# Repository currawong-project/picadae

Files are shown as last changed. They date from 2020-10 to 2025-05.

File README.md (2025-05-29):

# Currawong Picadae

The Currawong Picadae is a portable piano player unit inspired by
[PlayerPiano II](https://logosfoundation.org/instrum_gwr/playerpiano.html) as created by [Gotfried-Willem Raes](https://en.wikipedia.org/wiki/Godfried-Willem_Raes)
 of the [Logos Foundation](https://www.logosfoundation.org/).  This project
 was a [Currawong Project](https://currawongproject.org) collaboration with
 Bill Bowen and Chico McMurtrie of [Amorphic Robot Works](https://amorphicrobotworks.org/).

# CML Picadae hardware and a control files.

- [__kicad__](kicad/README.md) contains the keyboard and pedal schematics and printed circuit board layout.
- [__control__](control/README.md) contains the keyboard solenoid ATtiny85 firware, controller Arduino firmware and, Python control API and program.

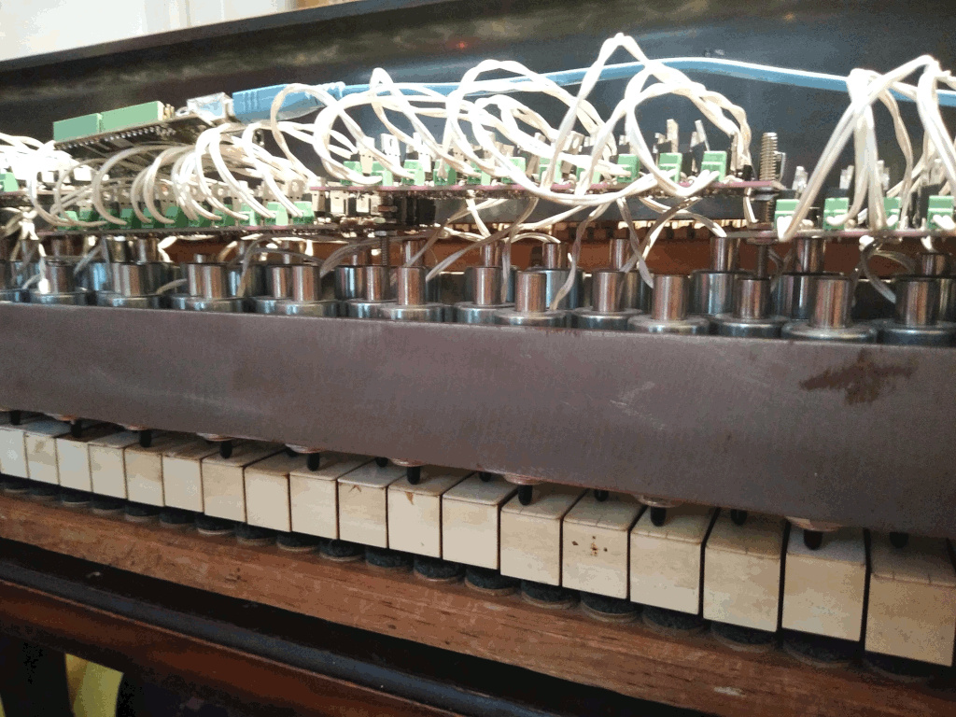
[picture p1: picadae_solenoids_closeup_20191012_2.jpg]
Picadae


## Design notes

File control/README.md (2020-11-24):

This folder contains the _picadae_ control code.

The _picadae_ control program consists of three parts:

- _tiny_ : [ATtiny85 solenoid driver firmware](tiny/README.md)

- _ctrl_ : [ATmega328 interface unit](ctrl/README.md) 

- _app_  : [Python monitor and command utility](app/README.md)

# Architecture

The keyboard control hardware consists of 8 driver boards mounted
above the solenoids on the keyboard assembly.  Each driver board has
11 key driver circuits which control 11 piano keys. Each key driver
circuit consists of an ATtiny85 microcontroller which controls a set
of power transistors which in turn control the state of the solenoid.
The solenoid can be in one of three states:

- off
- attack
- hold 

The attack state is triggered by pulsing the 
the solenoid with a fast (250 microsecond to
30 millisecond) 36 volt pulse. The duration
of the pulse determines the attack dynamic.
Longer pulses produce louder notes.
At the end of the attack state the solenoid
transitions into a hold state. During
this time the key is held down with just
enough force to sustain the note.

All 88 ATtiny85 microncontrollers are attached
to a single I2C bus which is mastered by an ATmega328 MCU
which acts as a serial to I2C translator for the host computer.

The host API is implemented as the Python class 'Picadae' in app/picadae_api.py.
The control shell program app/picadae_shell.py shows an example
usage of the API.

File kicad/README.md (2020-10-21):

# Bill of materials

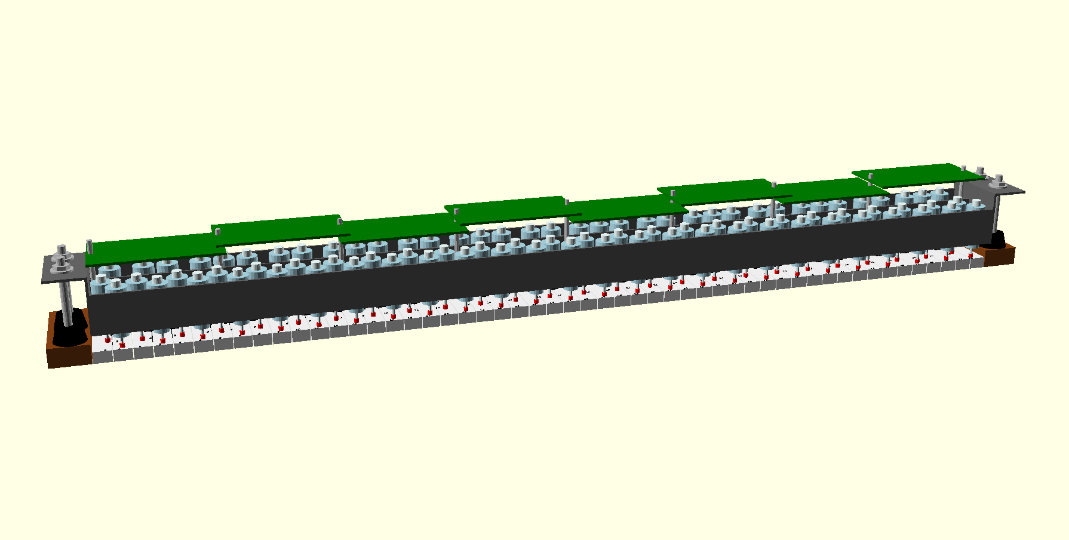
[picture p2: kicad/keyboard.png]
Keyboard assembly


## Keyboard Power and Control 

These parts serve the entire keyboard solenoid assembly.

Id   | Type            | Description          | Qty | Source   | Part Number
-----|-----------------|----------------------|-----|----------|--------------------
J3   | 6P Terminal     | Screw Terminal       |   2 | Mouser   | 651-1725698
P1   | HDS800PS24      | 24V Power Supply     |   1 | Digikey  | 1470-2689-ND
P2   | HDS800PS12      | 12V Power Supply     |   1 | Digikey  | 1470-2687-ND
P3   | TXL 015-05S     | 5V Power Supply      |   1 | Digikey  | 1951-1325-ND
M0   | Controller MCU  | Arduino Uno R3       |   1 | Digikey  | 1050-1024-ND
None | 1/16 x 1/8 x 1/2| Rubber feet(pkg 100) |   1 | McMaster | 9753K11

## Key Driver Board (11 channels per board) 

There are 8 driver boards per keyboard solenoid assembly. Each board
has 11 driver circuits.  

Id   | Type            | Description         | Qty | Source   | Part Number
-----|-----------------|---------------------|-----|----------|--------------------
U1   | ATtiny85-20MU   | Microcontroller     |  11 | Mouser   | 556-ATTINY85-20PU
None | 8DIP IC         | Socket              |  11 | Mouser   | 571-1-2199298-2
None | 0.1uF           | Capacitor           |   1 | Digikey  | 399-14010-1-ND
R1-2 | 4.7k            | Resistor            |  22 | Mouser   | 293-4.7K-RC
D1   | BYV32-200       | Diode               |  11 | Mouser   | BYV32-200GOS-ND
D2   | SF52            | Rectifier           |  11 | Mouser   | 583-SF52-B
D4   | Z10Y            | Diode               |  11 | Mouser   | 78-BZX55C10-TAP
Q1   | 2N3906          | BJT                 |  11 | Mouser   | 512-2N3906BU
Q2   | IRL640          | MOSFET              |  11 | Mouser   | 512-IRL640A
Q3   | IRF610          | MOSFET              |  11 | Mouser   | 844-IRF610PBF
S1   | Solenoid        | Ledex 195207-228    |  11 | Testco   | 195207-228
C1   | 100uF           | Capacitor           |   2 | Digikey  | 493-1668-ND
J1   | 2P Terminal     | Screw Terminal      |  11 | Mouser   | 651-1725656
J2   | 6P Female .1    | Pin Terminal        |   1 | Digikey  | H123900-ND

## Damper Pedal Driver Board

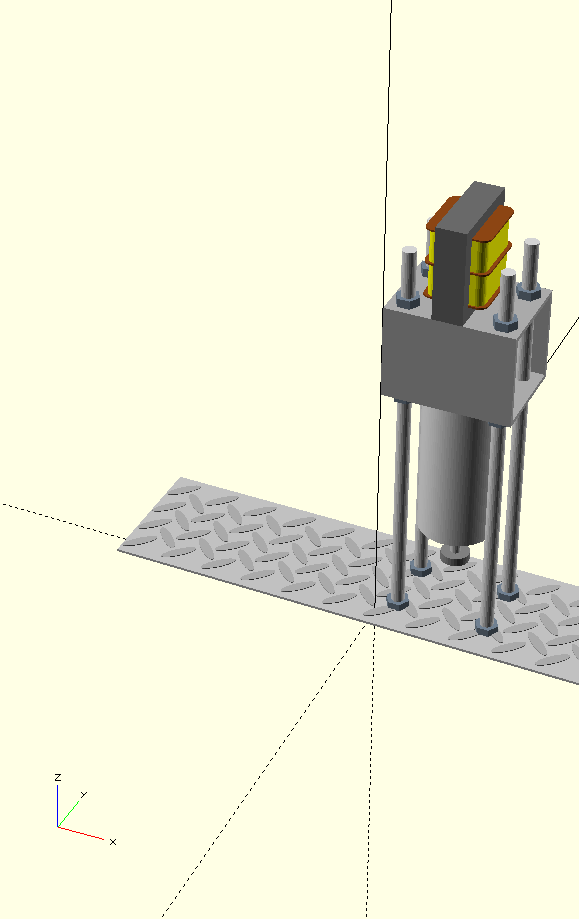
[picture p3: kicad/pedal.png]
Pedal driver assembly


Id   | Type            | Description         | Qty | Source   | Part Number
-----|-----------------|---------------------|-----|----------|--------------------
R1-4 | 180 ohm         | Resistor            |   4 |  Mouser  | 660-MF1/2LCT52R181G
R5-6 | 470 ohm         | Resistor            |   2 |  Mouser  | 71-CCF07470RGKE36
C1-2 | 1uF             | Capacitor           |   2 |  Newark  | 65R3171
C3-4 | 4700uF          | Capacitor           |   2 |  Newark  | GBPC2501W
Q1-2 | BS170           | MOSFET              |   2 |  Mouser  | 512-BS170
Q3-4 | IRF1310NPBF     | MOSFET              |   2 |  Mouser  | 942-IRF1310NPBF
U1   | TLP523          | Dual Opto-isolator  |   1 |  Newark  | 05M1443
U2-3 | LM7810ACT       | 10V Voltage Regulato|   2 |  Mouser  | 512-KA7810ETU
D1   | Bridge Rectifier| 100V 25A            |   1 |  Newark  | GBPC2501W
D2-3 | STTH30R061PI    | Diode               |   1 |  Mouser  | 512-RURP3060
L1   | Push Solenoid   | 24 Volt             |   1 |  Laukhuff| 301010
T1   | Transformer     |                     |   1 |  Digikey | 595-1961-ND

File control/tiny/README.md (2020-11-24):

# ATtiny85 I2C protocol

Arguments in curly braces are optional.

------------------------------------------------------------------------------------------

__Hold PWM Duty Cycle__

Function                 | Opcode | Arguments
-------------------------|--------|---------------------------
Set hold PWM duty cycle  |    0   | (duty) { (freq) { (div) }}

Arguments | Range | Default | Note
----------|-------|---------|------------------------------------------------------
(duty)    | 0-255 |    127  | 0=0%, 255=100%
(freq)    | 0-255 |    255  | Sets PWM top value
(div)     | 1-15  |      5  | Set the PWM base clock frequency (See table below) 

PWM frequency and period for each possible (div) setting.

Value | Div  | Frequency   | Period
------|------|-------------|-------
 1    |    1 |    16    M  | 62.5 n 
 2    |    2 |     8    M  |  125 n
 3    |    4 |     4    M  |  250 n
 4    |    8 |     2    M  |  500 n
 5    |   16 |     1    M  |    1 u
 6    |   32 |   500    K  |    2 u
 7    |   64 |   250    K  |    4 u
 8    |  128 |   125    K  |    8 u
 9    |  256 | 62500    Hz |   16 u
10    |  512 | 31250    Hz |   32 u
11    | 1024 | 15625    Hz |   64 u
12    | 2048 | 7812.5   Hz |  128 u
13    | 4096 | 3906.25  Hz |  256 u
14    | 8192 | 1953.125 Hz |  512 u
15    |16384 | 976.6625 Hz | 1024 u 

------------------------------------------------------------------------------------------

__Note-on Velocity__

Function                 | Opcode | Arguments
-------------------------|--------|---------------------------
Note on velocity         |    1   | (vel)

Arguments | Range | Default | Note
----------|-------|---------|------------------------------------------------------
(vel)     | 0-127 |  n/a    | Note on velocity.

Execute a note onset.
The (vel) value is translated to an attack pulse duration
by looking up the pulse tick count in the velocity table.

------------------------------------------------------------------------------------------

__Note-on Microseconds__

Function                 | Opcode | Arguments
-------------------------|--------|-------------------------------------------------
Note on ticks            |   2    | (pulse-ticks-high-byte) (pulse-ticks-low-byte)

Execute a note onset.
The 16 bit attack duration in ticks is calculated from microseconds.

    pulse-ticks = (usec / 1e6) * (16e6/256)

Where 16e6 is the system clock frequency and 256 is the timer0 clock divider.
`TCCR0B:C02,C01,C00 = 100b (4)`

ticks to micoseconds:

    usecs = (pulse-ticks * 1e6)*(256/16e6)

------------------------------------------------------------------------------------------

__Note-off__

Function                 | Opcode | Arguments
-------------------------|--------|---------------------------
Note off                 |   3    | None

Turn off a sounding note by settting the hold-voltage to 0.

------------------------------------------------------------------------------------------

__Set Read Address__

Function                 | Opcode | Arguments
-------------------------|--------|---------------------------
Set read address         |    4   | (src) {(addr)}

Set the source and address of the next I2C read request.

The read can come from one of three memory banks:
Register File, MIDI velocity table or EEPROM.
See the _Memory Source Id Table_ below for the (src) id values.

Arguments   | Range | Default | Note
------------|-------|---------|-------------------------------------------------------
(src)       | 0-2   |  n/a    | Memory location id. See _Memory Source Id Table_.
(addr)      | 0-255 |  n/a    | Offset from base address set by (src)

Memory Source Id Table

Id | Memory         | Note
---|----------------|-------------------------------
 0 | Register file  | See register table file
 1 | Velocity table | MIDI velocity to pulse ticks lookup table
 2 | EEPROM         | EEPROM data memory

------------------------------------------------------------------------------------------

__Write Memory__

Function                 | Opcode | Arguments
-------------------------|--------|--------------------------------------------
Write memory             |    5   | (addrFl + dest) {(addr)} (value0) ... (valueN)

Arguments   | Range | Default | Note
------------|-------|---------|----------------------------------------------------------------
(addrFl)    | 0,127 |    0    | Address flag. Set if second byte is an (addr) and not (value0)
(dest)      | 0-2   |  n/a    | Memory destination location. See _Memory Destination Id Table_.
(addr)      | 0-255 |  n/a    | Optional offset from base address set by (dest)

Memory Destination Id Table

Id | Memory         | Note
---|----------------|-------------------------------
 4 | Register file  | See register table file
 5 | Velocity table | MIDI velocity to pulse ticks lookup table
 6 | EEPROM         | EEPROM data memory

------------------------------------------------------------------------------------------

__Write Velocity Table to EEPROM__

Function                 | Opcode | Arguments
-------------------------|--------|---------------------------
Write velocity table     |    6   | 

Writes the MIDI velocity table from memory to EEPROM.

------------------------------------------------------------------------------------------

__Set Hold Delay__

Function                 | Opcode | Arguments
-------------------------|--------|---------------------------
Set hold delay           |    7   | { high {low}}

Set the length of the delay, in ticks, between when the attack pulse ends and when the
hold voltage is applied.
The high and low byte values are calculated identically to the
attack pulse duration values.

------------------------------------------------------------------------------------------

__Set *flags* variable__

Function                 | Opcode | Arguments
-------------------------|--------|---------------------------
Set flags variable       |    8   | (flags)

  7  |  6  |  5  |  4  |  3  |  2  |  1  |  0  
-----|-----|-----|-----|-----|-----|-----|-----
 n/a | n/a | n/a | n/a | n/a | n/a | n/a | HOA

_HOA_ : Set to apply the hold voltage at the beginning of the attack.

------------------------------------------------------------------------------------------

## Register File Address

Address | Label           | Note
--------|-----------------|------------------------------------------------------------------------------------------------
0       | Reg_Rd_Addr     | Next register file address to read.
1       | Table_Rd_Addr   | Next MIDI velocity address to read.
2       | EEPROM_Rd_Addr  | Next EEPROM address to read.
3       | Read_Src_Addr   | Source of the next I2C read request. See Memory Location Id table below.
4       | Reg_Wr_Addr     | Next register file address to write.
5       | Table_Rd_Addr   | Next MIDI velocity address to write.
6       | EEPROM_Rd_Addr  | Next EEPROM address to write.
7       | Write_Dst_Addr  | Destination of the next 'write operation'. See Memory Location id table below.
8       | Tmr_High_Addr   | Current attack pulse tick count high byte
9       | Tmr_Low_Addr    | Current attack pulse tick count low byte
10      | Tmr_Div_Addr    | Attack pulse counter frequency divider.
11      | Pwm_Duty_Addr   | Duty cycle of the hold PWM generator
12      | Pwm_Freq_Addr   | PWM counter max values. Determines the PWM frequency.
13      | Pwm_Div_Addr    | PWM clock divider
14      | State_Addr      | Current solenoied state.
15      | Error_Addr      | Error status
16      | Max_Tmr_Hi_Addr | Max attack pulse high byte tick count.
17      | Delay_High_Addr | Hold delay onset tick count high byte
18      | Delay_Low_Addr  | Hold delay onset tick count low byte
19      | Flags_Addr      | Binary variable field.

------------------------------------------------------------------------------------------

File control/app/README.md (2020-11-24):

# Picadea control and monitor shell

Shell commands:

key | Function         | Arguments                                  | Notes
----|------------------|--------------------------------------------|----------------------------------------------------------
q   | quit             |                                            |
?   | print usage      |                                            |
w   | write            | (i2c_addr) (reg_addr) (data0) ... (dataN)  |
r   | read             | (i2c_addr) (src) (reg_addr) (byteN)        | See [Memory Source Id Table](#memory-source-id-table).
v   | note-on          | (pitch) (vel)                              |
u   | note-on          | (pitch) (usec) (div)                       | See [Pulse Timer Divisor Table](#pulse-timer-divisor).
o   | note-off         | (pitch)                                    |
T   | set table        | (pitch) (vel) (usec)                       |
t   | get table        | (pitch) (vel)                              |
D   | set duty         | (pitch) (percent) {(hz) {(div)}}           |
d   | get duty         | (pitch)                                    |
H   | set hold delay   | (pitch) (usec)                             |
h   | get hold delay   | (pitch)                                    |
F   | set pwm freq     | (pitch) (hz)                               | 254=~123Hz
f   | get pwm freq     | (pitch)                                    |
I   | set pwm div      | (pitch) (div)                              | See [PWM Divisor Table](#pwm-divisor).
i   | get pwm div      | (pitch)                                    |
A   | set flags        | (pitch) (flags)                            |
a   | get flags        | (pitch)                                    |
W   | write table      | (pitch)                                    |
N   | note w/ duration | (pitch) (atkUs) (durMs)                    |
S   | seq              | (pitch) (atkUs) (durMs) (deltaUs) (noteN)  |
L   | log              | (level) (0-1)                              |

## PWM Divisor

Value | Div  | Frequency   | Period
------|------|-------------|-------
 1    |    1 |    16    M  | 62.5 n 
 2    |    2 |     8    M  |  125 n
 3    |    4 |     4    M  |  250 n
 4    |    8 |     2    M  |  500 n
 5    |   16 |     1    M  |    1 u
 6    |   32 |   500    K  |    2 u
 7    |   64 |   250    K  |    4 u
 8    |  128 |   125    K  |    8 u
 9    |  256 | 62500    Hz |   16 u
10    |  512 | 31250    Hz |   32 u
11    | 1024 | 15625    Hz |   64 u
12    | 2048 | 7812.5   Hz |  128 u
13    | 4096 | 3906.25  Hz |  256 u
14    | 8192 | 1953.125 Hz |  512 u
15    |16384 | 976.6625 Hz | 1024 u 

## Pulse Timer Divisor

Value | Divisor | Frequency  | Period
------|---------|------------|--------------
  1   |      1  | 16000000   |     62.5n
  2   |      8  |  2000000   |    500.0n
  3   |     64  |   250000   |      4.0u
  4   |    256  |    62500   |     16.0u
  5   |   1024  |    15625   |     64.0u

## Memory Source Id Table

Id | Memory         | Note
---|----------------|-------------------------------
 0 | Register file  | See register table file
 1 | Velocity table | MIDI velocity to pulse ticks lookup table
 2 | EEPROM         | EEPROM data memory

## Memory Destination Id Table

Id | Memory         | Note
---|----------------|-------------------------------
 4 | Register file  | See register table file
 5 | Velocity table | MIDI velocity to pulse ticks lookup table
 6 | EEPROM         | EEPROM data memory

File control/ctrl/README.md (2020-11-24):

# ATmega328 Interface Unit

This MCU acts as a serial to I2C translator for the host
computer.  The serial protocol implements two
interfaces.  One for read requests and another for write commands.

The data format of the write commands is given
in the ATtiny85 I2C protocol document.

Read requests return blocks of memory begining with the address
specified in the last 'Set read address' command.

## Read: Channel to Host

Read a `<count>` bytes from a channel beginning at offset = 'offset'

    'r' <i2c-addr> <offset> <count>

## Write: Host to Channel

Write `<count>` bytes from from the host to a channel

    'w' <i2c-addr> <register> <count> <value-0> <value-1> ... <value-n>

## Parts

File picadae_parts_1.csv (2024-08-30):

Picadae Parts and Prices: 11/2020
Power and Control
Id | Type | Description | Qty | Price |  | Source | Source Part Number
J3 | 6P Terminal | Screw Terminal | 2 | 4.52 | 9.04 | Mouser | 651-1725698
P1 | HDS800PS24 | 24V Power Supply | 1 | 380 | 380 | Digikey | 1470-2689-ND
P2 | HDS800PS12 | 12V Power Supply | 1 | 380 | 380 | Digikey | 1470-2687-ND
P3 | TXL 015-05S | 5V Power Supply | 1 | 31.3 | 31.3 | Digikey | 1951-1325-ND
M0 | Controller MCU | Arduino Uno R3 | 1 | 22 | 22 | Digikey | 1050-1024-ND
 | 1/16 x 1/8 x 1/2 | Rubber feet (pkg 100) | 1 | 3.37 | 3.37 | McMaster | 9753K31 or (9753K11?)
 |  |  |  |  | 825.71
Key Driver Board (11 channels per board)
Id | Type | Description | Qty | Price |  | Source | Source Part Number
U1 | ATtiny85-20MU | Microcontroller | 11 | 1.44 | 15.84 | Mouser | 556-ATTINY85-20PU
 | 8DIP IC Socket |  | 11 | 0.09 | 0.99 | Mouser | 571-1-2199298-2
 | 0.1uF | Capacitor | 1 |  |  | Digikey | 399-14010-1-ND
R1-2 | 4.7k | Resistor | 22 | 0.18 | 3.96 | Mouser | 293-4.7K-RC
D1 | BYV32-200 | Diode | 11 | 0.92 | 10.12 | Mouser | BYV32-200GOS-ND
D2 | SF52 | Rectifier | 11 | 0.58 | 6.38 | Mouser | 583-SF52-B
D4 | Z10Y | Diode | 11 | 0.17 | 1.87 | Mouser | 78-BZX55C10-TAP
Q1 | 2N3906 | BJT | 11 | 0.15 | 1.65 | Mouser | 512-2N3906BU
Q2 | IRL640 | MOSFET | 11 | 1.33 | 14.63 | Mouser | 512-IRL640A
Q3 | IRF610 | MOSFET | 11 | 0.5 | 5.5 | Mouser | 844-IRF610PBF
S1 | Solenoid | Ledex 195207-228 | 11 | 23.44 | 257.84 | Testco | 195207-228
C1 | 100uF | Capacitor | 2 | 0.65 | 0.65 | Digikey | 493-1668-ND
J1 | 2P Terminal | Screw Terminal | 11 | 1.41 | 15.51 | Mouser | 651-1725656
J2 | 6P Female .1 | Pin Terminal | 1 | 2.38 | 2.38 | Digikey | H123900-ND
PCB |  |  | 1 | 33.5 | 33.5 | OSHPark | https://oshpark.com/shared_projects/KJpxQLND
 |  |  |  |  | 370.82
Damper Pedal Driver Board
Id | Type | Description | Qty | Price |  | Source | Source Part Number
R1-4 | 180 ohm | Resistor | 4 | 0.12 | 0.48 | Mouser | 660-MF1/2LCT52R181G
R5-6 | 470 ohm | Resistor | 2 | 0.1 | 0.2 | Mouser | 71-CCF07470RGKE36
C1-2 | 1uF | Capacitor | 2 | 0.25 | 0.5 | Newark | 65R3171
C3-4 | 4700uF | Capacitor | 2 | 2.84 | 5.68 | Newark | GBPC2501W
Q1-2 | BS170 | MOSFET | 2 | 0.28 | 0.56 | Mouser | 512-BS170
Q3-4 | IRF1310NPBF | MOSFET | 2 | 1.26 | 2.52 | Mouser | 942-IRF1310NPBF
U1 | TLP523 | Dual Opto-isolator | 1 | 1.63 | 1.63 | Newark | 05M1443
U2-3 | LM7810ACT | 10V Voltage Regulator | 2 | 0.5 | 1 | Mouser | 512-KA7810ETU
D1 | Bridge Rectifier | 100V 25A | 1 | 3.72 | 3.72 | Newark | GBPC2501W
D2-3 | STTH30R061PI | Diode | 1 | 1 | 1 | Mouser | 512-RURP3060
L1 | Push Solenoid | 24 Volt | 1 | 272 | 272 | Laukhuff | 301010
T1 | Power Transformer |  | 1 | 111 | 111 | Digikey | 595-1961-ND
PCB |  |  | 1 | 63.2 | 63.2 | OSHPark | https://oshpark.com/shared_projects/2v44Tnyi
 |  |  |  |  | 463.49
 |  | Power/Control | 1 | 825.71 | 825.71
 |  | Key Driver Boards | 8 | 370.82 | 2966.56 | (8 eleven channel key driver boards = 88 keys)
 |  | Pedal Driver Board | 1 | 463.49 | 463.49
 |  |  |  |  | 4255.76

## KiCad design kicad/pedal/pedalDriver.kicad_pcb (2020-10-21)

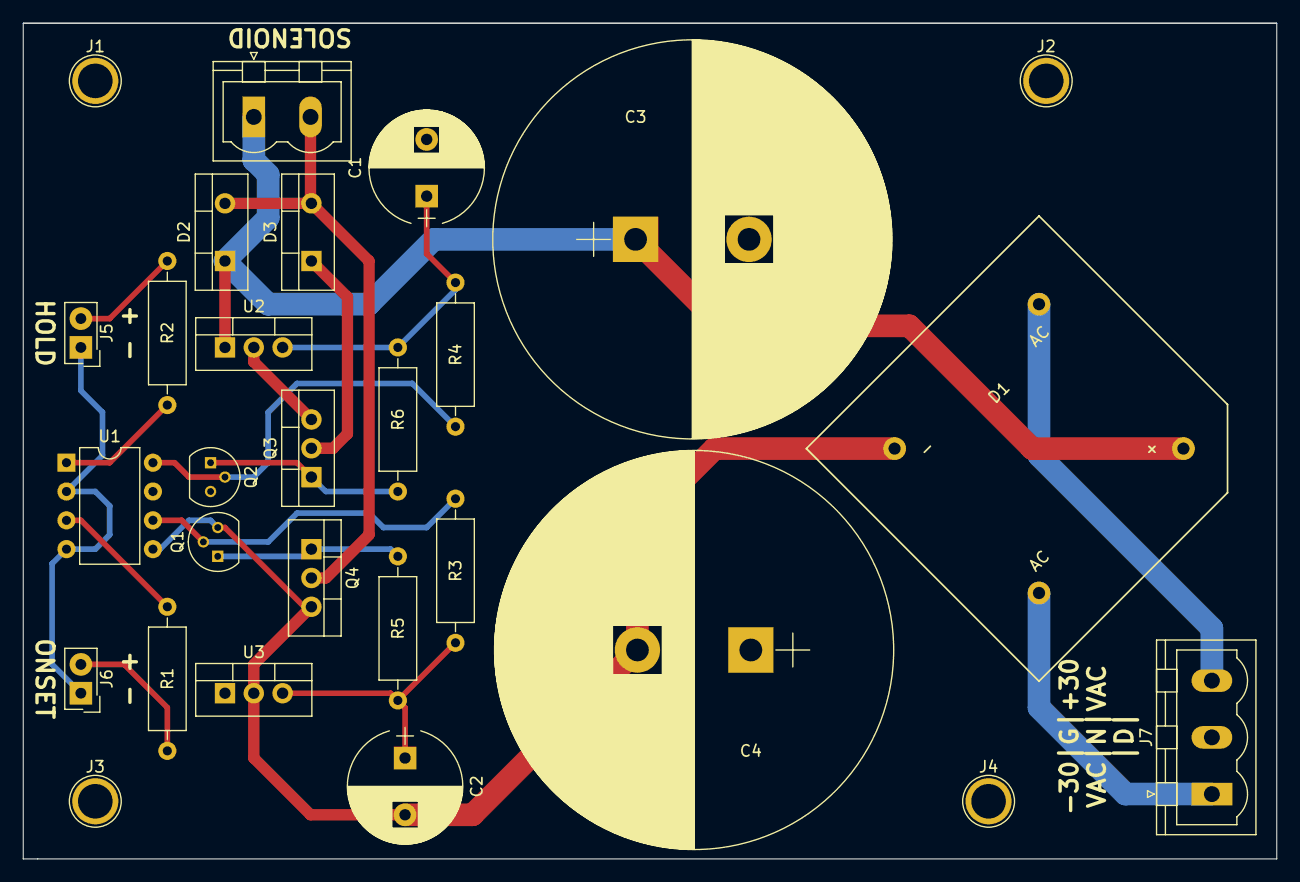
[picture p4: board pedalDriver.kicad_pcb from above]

Board: 2 copper layers, 110.5 x 73.7 mm, 28 parts (0 on the bottom side), 18 nets.

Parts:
C1, C2: 1µF; CP_Radial_D10.0mm_P5.00mm
C3, C4: 4700µF; CP_Radial_D35.0mm_P10.00mm_SnapIn
D1: D_Bridge_+-AA; GBPC-W
D2, D3: STTH30R061PI; TO-220-2_Vertical
J1, J2, J3, J4: CONN_01X01; 1pin
J5: HOLD; SL-102-X-XX_1x02
J6: ONSET; SL-102-X-XX_1x02
J7: -30, G, 30; PhoenixContact_MSTBVA-G_03x5.00mm_Vertical
Q1, Q2: BS170; TO-92_Molded_Narrow
Q3, Q4: IRF1310NPBF; TO-220-3_Vertical
R1, R2, R3, R4: 180Ω; R_Axial_DIN0309_L9.0mm_D3.2mm_P12.70mm_Horizontal
R5, R6: 470Ω; R_Axial_DIN0309_L9.0mm_D3.2mm_P12.70mm_Horizontal
Solenoid1: 20Ω; PhoenixContact_MSTBVA-G_02x5.00mm_Vertical
U1: TLP523-2; DIP-8_W7.62mm
U2, U3: LM7810ACT; TO-220-3_Vertical

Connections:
30VAC+: D1.3, J7.3
30VAC-: D1.4, J7.1
GND: C1.2, C3.2, C4.1, J7.2, Q2.3, Q3.3, U1.7, U2.2, U3.1
Hold: J5.2, R2.2
unnamed: C1.1, R4.2, R6.2, U2.3
unnamed: C2.1, R3.2, R5.2, U3.3
unnamed: C2.2, C4.2, D1.2, Q1.3, Q4.3, U1.5, U3.2
unnamed: C3.1, D1.1, D2.1, Solenoid1.1, U2.1
unnamed: D2.2, D3.2, Q4.2, Solenoid1.2
unnamed: D3.1, Q3.2
unnamed: Q1.1, Q4.1, R5.1
unnamed: Q1.2, R3.1, U1.6
unnamed: Q2.1, Q3.1, R6.1
unnamed: Q2.2, R4.1, U1.8
unnamed: R1.1, U1.3
unnamed: R2.1, U1.1
Onset: J6.2, R1.2
dGND: J5.1, J6.1, U1.2, U1.4

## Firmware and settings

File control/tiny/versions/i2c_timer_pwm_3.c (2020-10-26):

//| Copyright: (C) 2018-2020 Kevin Larke <contact AT larke DOT org>
//| License: GNU GPL version 3.0 or above. See the accompanying LICENSE file.

// w 60 0  1 10    : w i2c_addr SetPWM enable duty_val
// w 60 5 12  8 32 : w i2c_addr write addrFl|src coarse_val
// w 60 4  0  5    : w i2c_addr read  src read_addr  (set the read address to register 5)
// r 60 4  3       : r i2c_addr <dum> cnt            (read the first 3 reg's beginning w/ 5)
/*                                    
                                    AT TINY 85
                                     +--\/--+
                              RESET _| 1  8 |_ +5V
             ~OC1B       HOLD  DDB3 _| 2  7 |_ SCL         yellow 
              OC1B      ONSET  DDB4 _| 3  6 |_ DDB1 LED
                                GND _| 4  5 |_ SDA         orange
                                     +------+
        * = Serial and/or programming pins on Arduino as ISP
*/


// This program acts as the device (slave) for the control program i2c/a2a/c_ctl
#define F_CPU 16000000L

#include <stdio.h>
#include <avr/io.h>
#include <util/delay.h>
#include <avr/interrupt.h>

#include "usiTwiSlave.h"

#define HOLD_DIR DDB3
#define ATTK_DIR DDB4
#define LED_DIR  DDB1

#define HOLD_PIN PINB3
#define ATTK_PIN PINB4
#define LED_PIN  PINB1

// Opcodes
enum
{ 
 kSetPwm_Op         =  0,  // Set PWM duty/hz/div   0 {<duty> {<freq> {<div>}}}  div:2=2,3=4,4=8,5=16,6=32,7=64,8=128,9=256,10=512,11=1024,12=2048,13=4096,14=8192,15=16384
 kNoteOnVel_Op      =  1,  // Turn on note          3 {<vel>}
 kNoteOnUsec_Op     =  2,  // Turn on note          4 {<coarse> {<fine> {<prescale>}}}
 kNoteOff_Op        =  3,  // Turn off note         5
 kSetReadAddr_Op    =  4,  // Set a read addr.      6 {<src>} {<addr>} }  src: 0=reg 1=table 2=eeprom
 kWrite_Op          =  5,  // Set write             7 {<addrfl|src> {addr}  {<value0> ... {<valueN>}}  addrFl:0x80  src: 4=reg 5=table 6=eeprom
 kSetMode_Op        =  6,  // Set the mode flags    8 {<mode>}  1=repeat 2=pwm
 kWriteTable_Op     =  7,  // Write table to EEprom 9 
 kInvalid_Op        =  8   //                                             
};


enum
{
 kReg_Rd_Addr_idx    =  0,  // Next Reg Address to read
 kTable_Rd_Addr_idx  =  1,  // Next Table Address to read
 kEE_Rd_Addr_idx     =  2,  // Next EEPROM address to read
 kRead_Src_idx       =  3,  // kReg_Rd_Addr_idx=reg,  kTable_Rd_Addr_idx=table, kEE_Rd_Addr_idx=eeprom
 
 kReg_Wr_Addr_idx    =  4,  // Next Reg Address to write
 kTable_Wr_Addr_idx  =  5,  // Next Table Address to write
 kEE_Wr_Addr_idx     =  6,  // Next EEPROM address to write
 kWrite_Dst_idx      =  7,  // kReg_Wr_Addr_idx=reg,  kTable_Wr_Addr_idx=table, kEE_Wr_Addr_idx=eeprom
 
 kTmr_Coarse_idx     =  8,  //  
 kTmr_Fine_idx       =  9,  // 
 kTmr_Prescale_idx   = 10,  // Timer 0 clock divider: 1=1,2=8,3=64,4=256,5=1024  Default: 4 (16us)
 
 kPwm_Duty_idx       = 11,  // 
 kPwm_Freq_idx       = 12,  //
 kPwm_Div_idx        = 13,  //

 kMode_idx           = 14, // 1=repeat 2=pwm
 kState_idx          = 15, // 1=attk 2=hold
 kError_Code_idx     = 16, // Error Code
 kMax_idx
};

enum
{
 kMode_Repeat_Fl = 1,
 kMode_Pwm_Fl    = 2,
 kState_Attk_Fl        = 1,
 kState_Hold_Fl        = 2
};


#define isInRepeatMode() ctl_regs[ kMode_idx ] & kMode_Repeat_Fl
#define isInPwmMode()    ctl_regs[ kMode_idx ] & kMode_Pwm_Fl

// Flags:
// 1=Repeat: 1=Timer and PWM are free running. This allows testing with LED's. 0=Timer triggers does not reset on time out. 
// 2=PWM:  On timer timeout  1=PWM HOLD 0=Set HOLD 

volatile uint8_t ctl_regs[] =
{
   0,                //  0 (0-(kMax_idx-1)) Reg Read Addr   
   0,                //  1 (0-255)          Table Read Addr
   0,                //  2 (0-255)          EE Read Addr  
   kReg_Rd_Addr_idx, //  3 (0-2)    Read source
   
   0,                //  4 (0-(kMax_idx-1)) Reg Write Addr   
   0,                //  5 (0-255)          Table Write Addr
   0,                //  6 (0-255)          EE Write Addr
   kReg_Wr_Addr_idx, //  7 (0-2)    Write source
   
 245,                //  8 (0-255)  Timer 0 Coarse Value 
  25,                //  9 (0-255)  Timer 0 Fine Value
   4,                // 10 (1-5)    4=16us per tick
   
 127,                // 11 (0-255)  Pwm Duty cycle
 254,                // 12 (0-255)  Pwm Frequency  (123 Hz)
  10,                // 13 (0-15)   Pwm clock div 
   
   kMode_Repeat_Fl,  // 14 mode flags  1=Repeat 2=PWM
   0,                // 15 state flags 1=attk   2=hold  (read/only)
   0,                // 16 (0-255)  Error bit field    
};

// These registers are saved to Eeprom
uint8_t eeprom_addr[] =
{
 kTmr_Prescale_idx,
 kPwm_Duty_idx,
 kPwm_Freq_idx,
 kPwm_Div_idx
};



#define tableN 256
uint8_t table[ tableN ]; // [ coarse_0,fine_0, coarse_1, fine_1, .... coarse_127,fine_127]
 

enum
{
 kInvalid_Read_Src_ErrFl  = 0x01,
 kInvalid_Write_Dst_ErrFl = 0x02
};

#define set_error( flag ) ctl_regs[ kError_Code_idx ] |= (flag)

//------------------------------------------------------------------------------
//------------------------------------------------------------------------------
//------------------------------------------------------------------------------
//
// EEPROM
//

void EEPROM_write(uint8_t ucAddress, uint8_t ucData)
{
  // Wait for completion of previous write 
  while(EECR & (1<<EEPE))
  {}
    
  EECR = (0<<EEPM1)|(0<<EEPM0); // Set Programming mode   
  EEAR = ucAddress;             // Set up address and data registers 
  EEDR = ucData;  
  EECR |= (1<<EEMPE);           // Write logical one to EEMPE 
  EECR |= (1<<EEPE);            // Start eeprom write by setting EEPE 
}

uint8_t EEPROM_read(uint8_t ucAddress)
{
  // Wait for completion of previous write 
  while(EECR & (1<<EEPE))
  {}
    
  EEAR = ucAddress;  // Set up address register 
  EECR |= (1<<EERE); // Start eeprom read by writing EERE 
  return EEDR;       // Return data from data register 
}

void write_table()
{
  uint8_t i;
  uint8_t regN = sizeof(eeprom_addr);

  // write the persistent registers
  for(i=0; i<regN; ++i)
    EEPROM_write( i, ctl_regs[ eeprom_addr[i] ] );

  // write the table
  for(i=0; i<tableN; ++i)
    EEPROM_write( regN+i, table[i] );
}

void load_table()
{
  uint8_t i;
  uint8_t regN = sizeof(eeprom_addr);

  // read the persistent registers
  for(i=0; i<regN; ++i)
    ctl_regs[ eeprom_addr[i] ] = EEPROM_read(i);

  // read the tabke
  for(i=0; i<tableN; ++i)
    table[i] = EEPROM_read(regN + i);
}


//------------------------------------------------------------------------------
//------------------------------------------------------------------------------
//------------------------------------------------------------------------------
//
// Timer0
//

volatile uint8_t tmr0_state        = 0;    // current timer mode: 0=disabled 1=coarse mode, 2=fine mode 
volatile uint8_t tmr0_coarse_cur   = 0;

#define set_attack()    do { ctl_regs[kState_idx] |= kState_Attk_Fl;  PORTB |= _BV(ATTK_PIN);            } while(0)
#define clear_attack()  do { PORTB &= ~_BV(ATTK_PIN);           ctl_regs[kState_idx] &= ~kState_Attk_Fl; } while(0)


// Use the current tmr0 ctl_reg[] values to set the timer to the starting state.
void tmr0_reset()
{
  tmr0_coarse_cur       = 0;               // clear the coarse time counter
  ctl_regs[kState_idx] |= kState_Attk_Fl;  // set the attack state
  PORTB                |= _BV(ATTK_PIN);   // set the attack pin 
  
  // if a coarse count exists then go into coarse mode 
  if( ctl_regs[kTmr_Coarse_idx] > 0 )
  {
    tmr0_state = 1;
    OCR0A      = 0xff;
  }
  else // otherwise go into fine mode
  {
    tmr0_state = 2;
    OCR0A     = ctl_regs[kTmr_Fine_idx];
  }
  
  TIMSK |= _BV(OCIE0A);     // enable the timer interrupt
}

ISR(TIMER0_COMPA_vect)
{
  switch( tmr0_state )
  {
    case 0:
      // timer is disabled
      break;

    case 1: 
      // coarse mode
      if( ++tmr0_coarse_cur >= ctl_regs[kTmr_Coarse_idx] )
      {
        tmr0_state  = 2;
        OCR0A     = ctl_regs[kTmr_Fine_idx];        
      }
      break;

    case 2:
      // fine mode

      // This marks the end of a timer period 

      // If in repeat mode ...
      if(ctl_regs[kMode_idx] & kMode_Repeat_Fl)
      {
        // store the current state of the attack flag
        uint8_t fl = ctl_regs[kState_idx] & kState_Attk_Fl;
        
        tmr0_reset();  // ... restart the timer
        
        // ATTK_PIN is always set after tmr0_reset() but we need to toggle in 'repeat' mode
        if( fl )
        {
          clear_attack();
        }

        // In repeat mode we always run the PWM output continuously.
        // This guarantees that no matter how the modes may be changing that PWM will be enabled.
        TIMSK  |= _BV(OCIE1B) + _BV(TOIE1); // Enable PWM interrupts

      }
      else  // ... not in repeat mode
      {
        clear_attack();
        
        if( ctl_regs[kMode_idx] & kMode_Pwm_Fl)
        {
          TIMSK  |= _BV(OCIE1B) + _BV(TOIE1);    // PWM interupt Enable interrupts          
        }
        else
        {
          PORTB |= _BV(HOLD_PIN); // set the HOLD pin          
        }

        TIMSK &= ~_BV(OCIE0A);   // clear timer interrupt
        
      }
      
      break;
  }
}


void tmr0_init()
{
  TIMSK  &= ~_BV(OCIE0A);                 // Disable interrupt TIMER1_OVF
  TCCR0A  |=  0x02;                       // CTC mode
  TCCR0B  |= ctl_regs[kTmr_Prescale_idx]; // set the prescaler
  GTCCR   |= _BV(PSR0);                   // Set the pre-scaler to the selected value
}


//------------------------------------------------------------------------------
//------------------------------------------------------------------------------
//------------------------------------------------------------------------------
//
// Pwm
//
// PWM is optimized to use pins OC1A ,~OC1A, OC1B, ~OC1B
// but since these pins are not available this code uses
// ISR's to redirect the output to PIN3

void pwm1_update()
{
  OCR1B   = ctl_regs[kPwm_Duty_idx]; // control duty cycle
  OCR1C   = ctl_regs[kPwm_Freq_idx]; // PWM frequency pre-scaler
}



ISR(TIMER1_OVF_vect)
{
  PORTB |= _BV(HOLD_PIN);  // set PWM pin
}

ISR(TIMER1_COMPB_vect)
{
  PORTB &= ~(_BV(HOLD_PIN)); // clear PWM pin
}


void pwm1_init()
{
  TIMSK  &= ~(_BV(OCIE1B) + _BV(TOIE1));    // Disable interrupts
  
  DDRB   |=  _BV(HOLD_DIR);  // setup PB3 as output  

  // set on TCNT1 == 0     // happens when TCNT1 matches OCR1C
  // clr on OCR1B == TCNT  // happens when TCNT1 matches OCR1B
  //                       // COM1B1=1 COM1B0=0 (enable output on ~OC1B)
  TCCR1  |= ctl_regs[ kPwm_Div_idx];    // 32us period (512 divider) prescaler
  GTCCR  |= _BV(PWM1B);    // Enable PWM B and disconnect output pins
  GTCCR  |= _BV(PSR1);     // Set the pre-scaler to the selected value

  pwm1_update();
}

//------------------------------------------------------------------------------
//------------------------------------------------------------------------------
//------------------------------------------------------------------------------

// Tracks the current register pointer position
volatile uint8_t reg_position = 0;
const uint8_t    reg_size = sizeof(ctl_regs);

//
// Read Request Handler
//
// This is called for each read request we receive, never put more
// than one byte of data (with TinyWireS.send) to the send-buffer when
// using this callback
//

void on_request()
{
  uint8_t val = 0;
  
  switch( ctl_regs[ kRead_Src_idx ] )
  {
    case kReg_Rd_Addr_idx:
      val = ctl_regs[ ctl_regs[kReg_Rd_Addr_idx] ];
      break;

    case kTable_Rd_Addr_idx:
      val = table[ ctl_regs[kTable_Rd_Addr_idx] ];
      break;

    case kEE_Rd_Addr_idx:
      val = EEPROM_read(ctl_regs[kEE_Rd_Addr_idx]);
      break;

    default:
      set_error( kInvalid_Read_Src_ErrFl );
      return;
  }
  
  usiTwiTransmitByte(val);

  ctl_regs[ ctl_regs[ kRead_Src_idx ]  ] += 1;

}


void _write_op( uint8_t* stack, uint8_t stackN )
{
  uint8_t stack_idx = 0;
  
  if( stackN > 0 )
  {
    uint8_t src     = stack[0] & 0x07;
    uint8_t addr_fl = stack[0] & 0x08;

    // verify the source value
    if( src < kReg_Wr_Addr_idx  || src > kEE_Wr_Addr_idx )
    {
      set_error( kInvalid_Write_Dst_ErrFl );
      return;
    }

    // set the write source
    stack_idx                  = 1;
    ctl_regs[ kWrite_Dst_idx ] = src;

    // if an address value was passed also ....
    if( addr_fl && stackN > 1 )
    {
      stack_idx       = 2;
      ctl_regs[ src ] = stack[1];
    }
  }

  //
  for(; stack_idx<stackN; ++stack_idx)
  {
    uint8_t addr_idx = ctl_regs[ ctl_regs[kWrite_Dst_idx] ]++;
    uint8_t val      = stack[ stack_idx ];
    
    switch( ctl_regs[ kWrite_Dst_idx ] )
    {
      case kReg_Wr_Addr_idx:   ctl_regs[ addr_idx ]           = val;  break;
      case kTable_Wr_Addr_idx: table[ addr_idx ]              = val;  break;
      case kEE_Wr_Addr_idx:    EEPROM_write( table[ addr_idx ], val); break;

      default:
        set_error( kInvalid_Write_Dst_ErrFl );
        break;
    }
  }
}

//
// The I2C data received -handler
//
// This needs to complete before the next incoming transaction (start,
// data, restart/stop) on the bus does so be quick, set flags for long
// running tasks to be called from the mainloop instead of running
// them directly,
//

void on_receive( uint8_t byteN )
{
  PINB = _BV(LED_PIN);  // writes to PINB toggle the pins

  const uint8_t stackN = 16;
  uint8_t stack_idx = 0;
  uint8_t stack[ stackN ];
  uint8_t i;
  
  if (byteN < 1 || byteN > TWI_RX_BUFFER_SIZE)
  {
    // Sanity-check
    return;
  }

  // get the register index to read/write
  uint8_t op_id = usiTwiReceiveByte();
    
  byteN--;

  // If only one byte was received then this was a read request
  // and the buffer pointer (reg_position) is now set to return the byte
  // at this location on the subsequent call to on_request() ...
  if(byteN)
  {
    while( byteN-- )
    {  
      stack[stack_idx] = usiTwiReceiveByte();
      ++stack_idx;
    }
  }
  
  switch( op_id )
  {
    case kSetPwm_Op:
      for(i=0; i<stack_idx && i<3; ++i)
        ctl_regs[ kPwm_Duty_idx + i ] = stack[i];

      // if the PWM prescaler was changed
      if( i == 3 )
        pwm1_init();
          
      pwm1_update();
      break;

      
    case kNoteOnUsec_Op:
      for(i=0; i<stack_idx && i<3; ++i)
        ctl_regs[ kTmr_Coarse_idx + i ] = stack[i];

      // if a prescaler was included then the timer needs to be re-initialized
      if( i == 3 )
        tmr0_init();
      
      tmr0_reset();
      break;

    case kNoteOff_Op:
      TIMSK  &= ~_BV(OCIE0A);                // clear timer interrupt (shouldn't be necessary)
      TIMSK  &= ~(_BV(OCIE1B) + _BV(TOIE1)); // PWM interupt disable interrupts          
      PORTB  &= ~_BV(HOLD_PIN);              // clear the HOLD pin
      break;

    case kSetReadAddr_Op:
      if( stack_idx > 0 )
      {
        ctl_regs[ kRead_Src_idx ] = stack[0];
      
        if( stack_idx > 1 )
          ctl_regs[ ctl_regs[ kRead_Src_idx ] ] = stack[1];
      }
      break;

    case kWrite_Op:
      _write_op( stack, stack_idx );
      break;

    case kSetMode_Op:
      if( stack_idx > 0)
      {
        ctl_regs[ kMode_idx ] = stack[0];

        // if repeat mode was enabled
        if( ctl_regs[ kMode_idx ] & kMode_Repeat_Fl )
          tmr0_reset();
        
        pwm1_init();  // the state of PWM may have been changed
      }
      break;

    case kWriteTable_Op:
      write_table();
      break;
  }
}


int main(void)
{
  cli();        // mask all interupts

  DDRB  |=   _BV(ATTK_DIR)  + _BV(HOLD_DIR)  + _BV(LED_DIR);  // setup PB4,PB3,PB1 as output  
  PORTB &= ~(_BV(ATTK_PIN)  + _BV(HOLD_PIN)  + _BV(LED_PIN)); // clear output pins
  
  tmr0_init();
  pwm1_init();
  
  // setup i2c library
  usi_onReceiverPtr = on_receive; 
  usi_onRequestPtr  = on_request;
  usiTwiSlaveInit(I2C_SLAVE_ADDRESS);
  
  sei();

  PINB = _BV(LED_PIN);  // writes to PINB toggle the pins
  _delay_ms(1000);  
  PINB = _BV(LED_PIN);  // writes to PINB toggle the pins

  // if in repeat mode
  if( ctl_regs[ kMode_idx ] & kMode_Repeat_Fl)
    tmr0_reset();
  
  while(1)
  {

    if (!usi_onReceiverPtr)
    {
        // no onReceive callback, nothing to do...
      continue;
    }
    
    if (!(USISR & ( 1 << USIPF )))
    {
        // Stop not detected
      continue;
    }

    
    uint8_t amount = usiTwiAmountDataInReceiveBuffer();
    if (amount == 0)
    {
        // no data in buffer
      continue;
    }

    
    usi_onReceiverPtr(amount);

    
  }
  return 0;
}

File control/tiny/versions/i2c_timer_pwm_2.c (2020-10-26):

//| Copyright: (C) 2018-2020 Kevin Larke <contact AT larke DOT org>
//| License: GNU GPL version 3.0 or above. See the accompanying LICENSE file.

/*                                    
                                    AT TINY 85
                                     +--\/--+
                              RESET _| 1  8 |_ +5V
             ~OC1B       HOLD  DDB3 _| 2  7 |_ SCL
              OC1B      ONSET  DDB4 _| 3  6 |_ DDB1 LED
                                GND _| 4  5 |_ SDA
                                     +------+
        * = Serial and/or programming pins on Arduino as ISP
*/


// This program acts as the device (slave) for the control program i2c/a2a/c_ctl

#define F_CPU 8000000L
#include <stdio.h>
#include <avr/io.h>
#include <util/delay.h>
#include <avr/interrupt.h>

#include "usiTwiSlave.h"

#define HOLD_DIR DDB3
#define ATTK_DIR DDB4
#define LED_DIR  DDB1

#define HOLD_PIN PINB3
#define ATTK_PIN PINB4
#define LED_PIN  PINB1

// Opcodes
enum
{ 
 kSetReg_Op         =  0,  // Set register  <hi_addr> <lo_addr> <value0> ... <valueN>
 kSetPwm_Op         =  1,  // Set PWM registers <enable> <duty> <freq>
 kNoteOnVel_Op      =  2,  // Turn on note <vel>
 kNoteOnUsec_Op     =  3,  // Turn on note <coarse> <fine>
 kNoteOff_Op        =  4,  // Turn off note
 kRead_Op           =  5,  // Read a value {{ <src>} <addr> }
 kInvalid_Op        =  6
};


// Register addresses
enum
{
 kTmr_Coarse_idx     =  0,  // Current Timer 0 coarse count
 kTmr_Fine_idx       =  1,  // Current Timer 0 fine count
 kTmr_Prescale_idx   =  2,  // Current Timer 0 clock divider: 1=1,2=8,3=64,4=256,5=1024
 kPwm_Enable_idx     =  3,  // Current PWM 1 enable flag
 kPwm_Duty_idx       =  4,  // Current PWM 1 duty cycle
 kPwm_Freq_idx       =  5,  // Current PWM 1 frequency
 kRead_Src_idx       =  6,  // 0=reg, 1=table, 2=eeprom
 kReg_Addr_idx       =  7,  // Next Reg Address to read
 kTable_Addr_idx     =  8,  // Next Table Address to read
 kEE_Addr_idx        =  9,  // Next EEPROM address to read
 kError_Code_idx     = 10,  // Error Code
 kMax_idx
};

// Regster memory
volatile uint8_t ctl_regs[] =
{
 
 123,    //  1 (0-255)  Timer 0 Coarse Value 
   8,    //  2 (0-255)  Timer 0 Fine Value
   4,    //  0 (1-5)    4=32us per tick

   1,    //  5 (0-1)   PWM1 Enable 
 127,    //  3 (0-255) PWM1 Duty cycle (0-100%)
 254,    //  4 (0-255) PWM1 Frequency  (123 hz)

   0,    //  6 (0-255) Read Source 
   0,    //  7 (0-255) Reg addr   
   0,    //  8 (0-255) Table addr
   0,    //  9 (0-255) EEPROM addr

   0,    // 10 (0-255) Error code
   
};

volatile uint8_t table[128];



#define stackN 16 
volatile uint8_t stack[ stackN ];

//------------------------------------------------------------------------------
//------------------------------------------------------------------------------
//------------------------------------------------------------------------------
//
// EEPROM
//

void EEPROM_write(uint8_t ucAddress, uint8_t ucData)
{
  // Wait for completion of previous write 
  while(EECR & (1<<EEPE))
  {}
    
  EECR  = (0<<EEPM1)|(0<<EEPM0);      // Set Programming mode   
  EEARH = 0;                          // Set up address and data registers
  EEARL = ucAddress;
  EEDR  = ucData;  
  EECR |= (1<<EEMPE);                // Write logical one to EEMPE 
  EECR |= (1<<EEPE);                 // Start eeprom write by setting EEPE 
}


uint8_t EEPROM_read(uint8_t ucAddress)
{
  // Wait for completion of previous write 
  while(EECR & (1<<EEPE))
  {}
    
  EEARH = 0;                          // Set up address and data registers
  EEARL = ucAddress;
  EECR |= (1<<EERE);                 // Start eeprom read by writing EERE 
  return EEDR;                       // Return data from data register 
}

//------------------------------------------------------------------------------
//------------------------------------------------------------------------------
//------------------------------------------------------------------------------
//
// Read/Write table
//

#define eeprom_addr( addr ) (addr)


void table_load( void )
{
  uint8_t i = 0;

  for(; i<64; ++i)
  {
    uint16_t tbl_addr  = i*2;
    table[tbl_addr+0] = EEPROM_read( eeprom_addr(tbl_addr+0) );
    table[tbl_addr+1] = EEPROM_read( eeprom_addr(tbl_addr+1) );
  }  
}

void restore_memory_from_eeprom( void )
{
  /*
  uint8_t i;
  for(i=0; i<kMax_idx; ++i)
  {
    ctl_regs[i] = EEPROM_read( eeprom_addr( i ) );
  }
  */
  
  table_load();
}


//------------------------------------------------------------------------------
//------------------------------------------------------------------------------
//------------------------------------------------------------------------------
//
// Timer0
//

volatile uint8_t tmr0_state        = 0;    // 0=disabled 1=coarse mode, 2=fine mode 
volatile uint8_t tmr0_coarse_cur   = 0;

// Use the current tmr0 ctl_reg[] values to set the timer to the starting state.
void tmr0_reset()
{
  // if a coarse count exists then go into coarse mode 
  if( ctl_regs[kTmr_Coarse_idx] > 0 )
  {
    tmr0_state = 1;
    OCR0A      = 0xff;
  }
  else // otherwise go into fine mode
  {
    tmr0_state = 2;
    OCR0A     = ctl_regs[kTmr_Fine_idx];
  }
  
  tmr0_coarse_cur = 0;  
}

ISR(TIMER0_COMPA_vect)
{
  switch( tmr0_state )
  {
    case 0:
      // disabled
      break;

    case 1: 
      // coarse mode
      if( ++tmr0_coarse_cur >= ctl_regs[kTmr_Coarse_idx] )
      {
        tmr0_state  = 2;
        OCR0A     = ctl_regs[kTmr_Fine_idx];        
      }
      break;

    case 2:
      // fine mode
      PINB = _BV(ATTK_PIN);  // writes to PINB toggle the pins

      tmr0_reset(); // restart the timer 
      break;
  }
}


void timer0_init()
{
  TIMSK  &= ~_BV(OCIE0A);    // Disable interrupt TIMER0_COMPA_vect
  TCCR0A  |=  0x02;           // CTC mode
  TCCR0B  |= ctl_regs[kTmr_Prescale_idx]; // set the prescaler

  GTCCR  |= _BV(PSR0);      // Set the pre-scaler to the selected value
  
  tmr0_reset();              // set the timers starting state
  
  TIMSK  |= _BV(OCIE0A);     // Enable interrupt TIMER0_COMPA_vect

}





//------------------------------------------------------------------------------
//------------------------------------------------------------------------------
//------------------------------------------------------------------------------
//
// PWM1
//
// PWM is optimized to use pins OC1A ,~OC1A, OC1B, ~OC1B but this code
// but since these pins are not available this code uses
// ISR's to redirect the output to PIN3

void pwm1_update()
{
  OCR1B   = ctl_regs[kPwm_Duty_idx]; // control duty cycle
  OCR1C   = ctl_regs[kPwm_Freq_idx]; // PWM frequency pre-scaler
}

ISR(TIMER1_OVF_vect)
{
    PORTB |= _BV(HOLD_PIN);  // set PWM pin
}

ISR(TIMER1_COMPB_vect)
{
  PORTB &= ~(_BV(HOLD_PIN)); // clear PWM pin
}
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

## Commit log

2019-07-14 i2c_timer_pwm.c initial PWM initialization.
2019-07-14 Initial working version of long interval timer and PWM under the control of picadae_cmd.py.
2019-07-20 picadae_cmd.py : changed serial output to show all received data in integer format. ctrl/main.c : write commands now send as many data bytes as received rather than just 2. tiny/main.c : Added timer0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
    [i2c_timer_pwm.c, main.c]
2019-08-03 Updates for initial timer and pwm test on piccadae.
2019-08-08 ctrl/main.c, tiny/i2c_timer_pwm.c : Updated comments.
2019-09-01 Added earlier and extended versions of picadae/tiny/i2c_timer_pwn*.c in the folder picadae/tiny/versions
2019-09-14 Clear TCNTx registers at start of attack and hold. Reverse polarity of hold output.
    [i2c_timer_pwm.c]
2019-11-18 picadae/tiny/i2c_timer_pwm.c : Added 'hold_state' to cleanly set the enable/disable PCM.
2019-11-18 picadae/app/picadae_api.py, picadae_shell.py : Updated PWM settters and getters.
2020-10-21 kicad/ : Initial commit
    [pedalDriver.kicad_pcb, pedalDriver3.sch, stackedDriver.kicad_pcb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]
2020-10-21 kicad/README.md : initial commit
2020-10-21 kicad/README.md : More updates.
2020-10-21 kicad/README.md,keyboard.png,pedal.png : Add images to the kicad readme.
2020-10-21 kicad/keyboard.png : Updated
2020-10-26 LICENSE and COPYRIGHT : Initial commit. Added license notice to all code files and schematics.
    [stackedDriver.sch]
2020-11-22 tiny/i2c_timer_pwm.c : Added hold delay and other changes to validate operation after logic analyzer analysis.
2020-11-22 app/picadae_api.py, picadae_shell.py : Added set/get_hold_delay(). Fixed shell._read().
    [picadae_api.py]
2020-12-07 tiny/usiTwiSlave.h/c : Make usi_onRequestPtr,usi_onRecievePtr extern and include <stdddef.h> to fix compilation errors apparently caused by new version of compiler.
    [usiTwiSlave.c]
2020-12-07 tiny/i2c_timer_pwm_2.c,tinyMakefile : New firmware version with programmable hold delay.
2024-08-30 Added parts list.
    [picadae_parts_1.csv]
2024-08-30 Update parts list and README.md
    [picadae_parts_1.csv]
